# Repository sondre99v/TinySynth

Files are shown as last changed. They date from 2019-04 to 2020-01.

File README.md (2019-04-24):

# TinySynth
A business card with a digital synthesizer, built with the [ATtiny817](https://www.microchip.com/wwwproducts/en/ATTINY817) microcontroller.

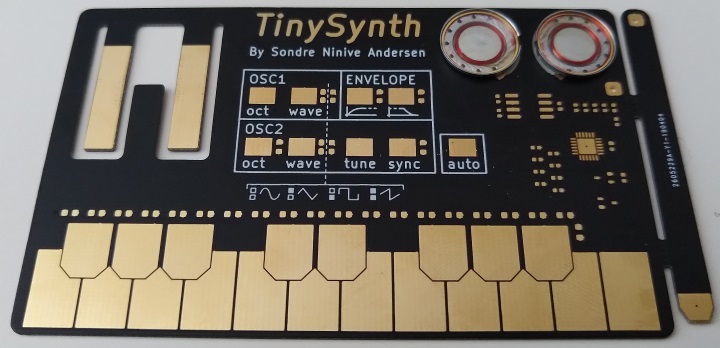
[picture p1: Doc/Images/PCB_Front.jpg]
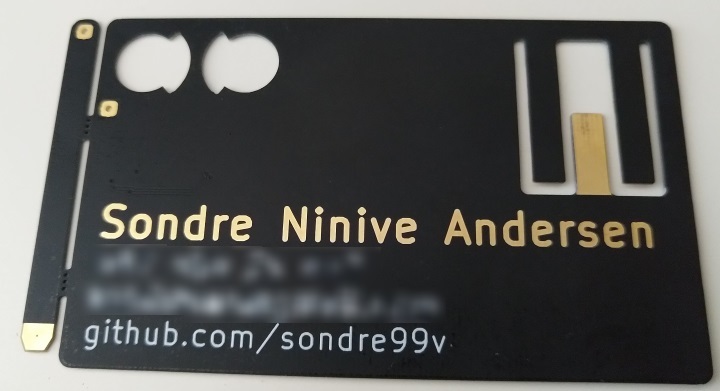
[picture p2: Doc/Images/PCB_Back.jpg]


## Features
The business card features my name, contact information, and a digital synthesizer with integrated speakers and keyboard. To use the synthesizer, insert a suitable 3V coin cell battery (CR2016 or CR2032 works), and break off the stylus on the right side of the card. The stylus can then be used to play the keyboard, or to configure the synthesizer with the buttons above the keys.

### Configuration
The synthesizer can be configured using the buttons above the keys. The buttons, from 1 to 8 have the following functions:
  * Oscillator 1 octave: Cycle the octave of oscillator 1 between three settings
  * Oscillator 1 wavefrom: Cycle the waveform of oscillator 1 between sine, square, triangle, and sawtooth
  * Envelope rise time: Toggle slow attack on the envelope
  * Envelope fall time: Toggle slow release on the envelope
  * Oscillator 2 octave / disable: Cycle the octave of oscillator 2 between three settings, or disable oscillator 2
  * Oscillator 2 waveform: Cycle the waveform of oscillator 2 between sine, square, triangle, and sawtooth
  * Oscillator 2 detuning: Cycle the interval of oscillator 2 (above oscillator 1) between unison, third, fifth, and seventh
  * Oscillator 2 synchronize: Enable oscillator 2 reset on each completed period of oscillator 1
    
## Hardware
### Keyboard
The keyboard is designed to be read by the microcontroller with an ADC input. The current keyboard is the third revision of the circuit. 

The first design used a simple voltage divider with an 100 ohm resistor between each key, to generate a unique voltage on each key. The stylus was connected to the ADC input, and was used to sample the voltages. This did not work very well, as a very weak pull-resistor was needed on the stylus, but it was weak enough that just touching it caused disturbance to the voltage.

The second design was more similar to the traditional method used for analog synthesizers. The keys was again connected with 100 ohm resistors, but this time a simple current-mirror circuit was used to drive a constant current through the chain. The stylus was grounded, and when touched to a key it provided a shorter circuit to ground lowering the voltage needed to drive this current. This current was then measured by the ADC. This worked, but was sensitive to changes in supply voltage, and did not give very reliable measurements.

The third and current revision is similar to the second design, but it replaces the constant current driver with a simple resistor. The keyboard forms a simple voltage divider with a fixed top resistor of 10K ohm, and the resistor chain between the keys makes up the bottom resistor. As the sampled voltage is non-linearly related to the bottom resistor, the resistor values betwwen the keys were adjusted to compensate. Some non-linearity was allowed (and is corrected for in the software) to allow use of standard resistor values, and reduce the number of unique BOM items.

### Speakers
The speakers are very thin speakers which I believe is intended to be used in earbuds. They are connected in series, and driven using a speaker-driver amplifying the filtered output signal from the DAC in the microcontroller.

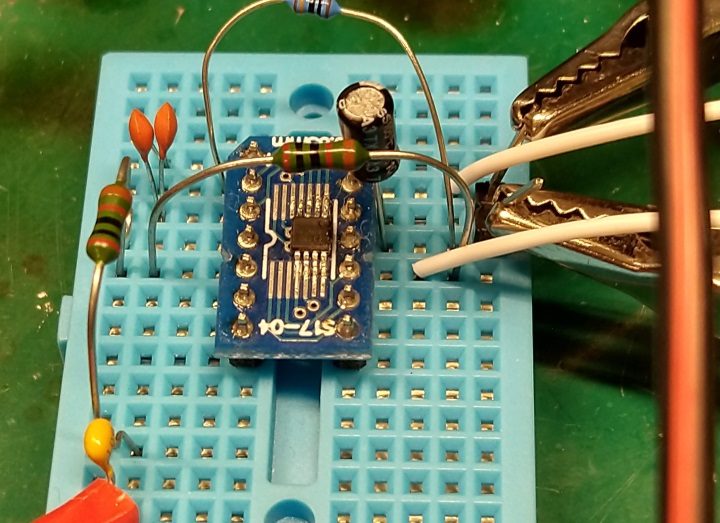
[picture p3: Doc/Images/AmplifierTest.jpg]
Prototyping of the amplifier circuit


### Battery
The battery holder was designed into the PCB to allow the business card to remain as thin as possible. Some testing was done in advance (by dremeling a 1.6mm PCB to test-fit a battery) but mostly the design was copied from various online inspirations. This design worked really well on the first prototype PCB, so no modification was required, other than to add an indication of the correct polarity of the battery.

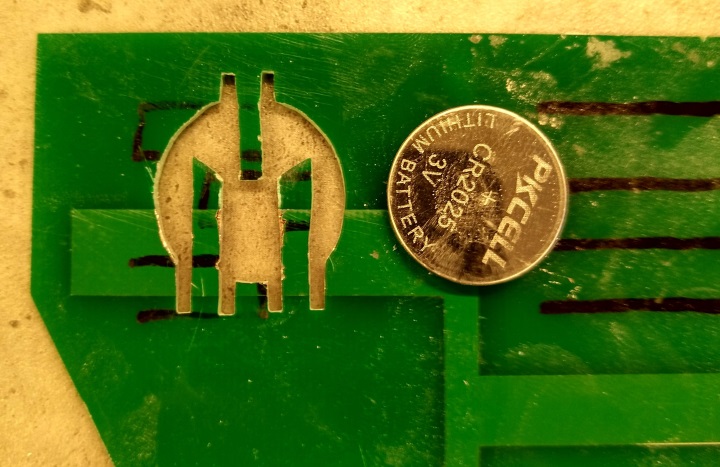
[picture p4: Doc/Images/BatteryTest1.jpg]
Initial test of battery holder
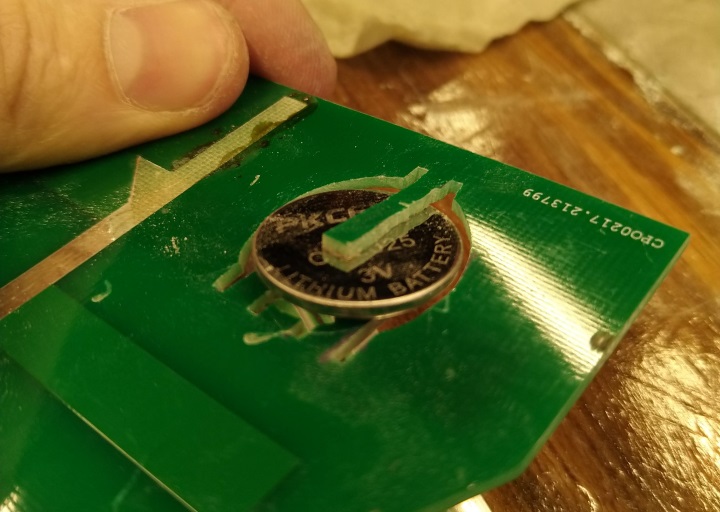
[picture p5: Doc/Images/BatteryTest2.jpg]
Initial test of battery holder
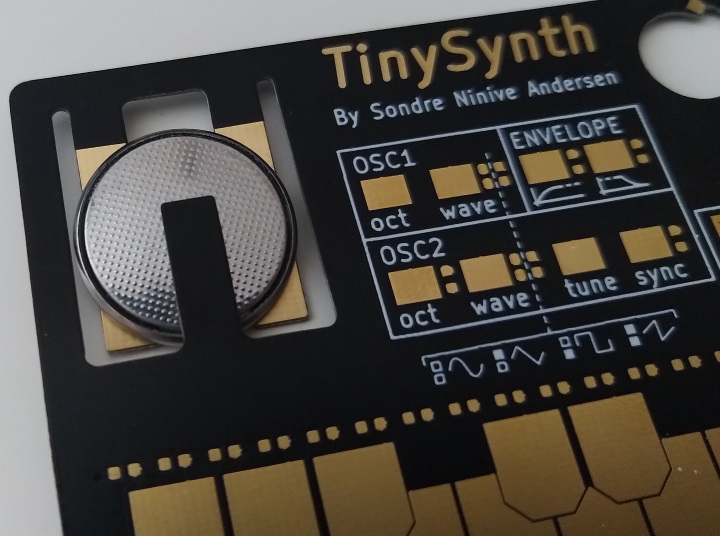
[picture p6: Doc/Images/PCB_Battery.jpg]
Battery holder on revision 1


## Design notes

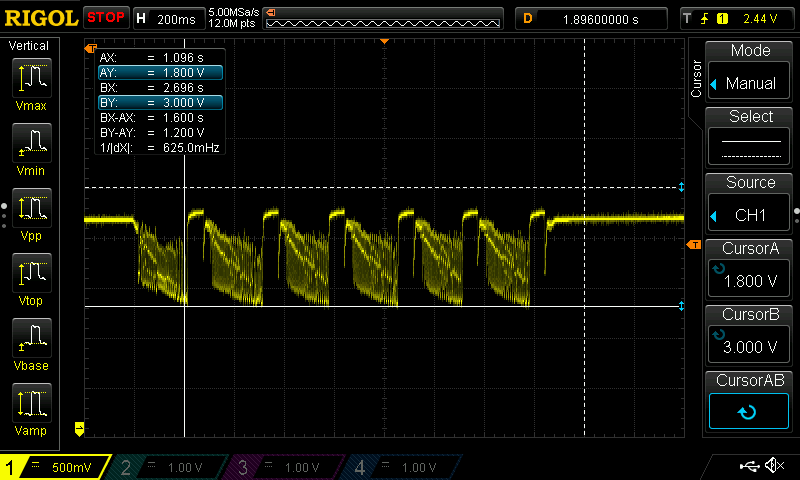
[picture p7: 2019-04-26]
Doc/Images/VoltageDrop/2_BattLow_BOD.png

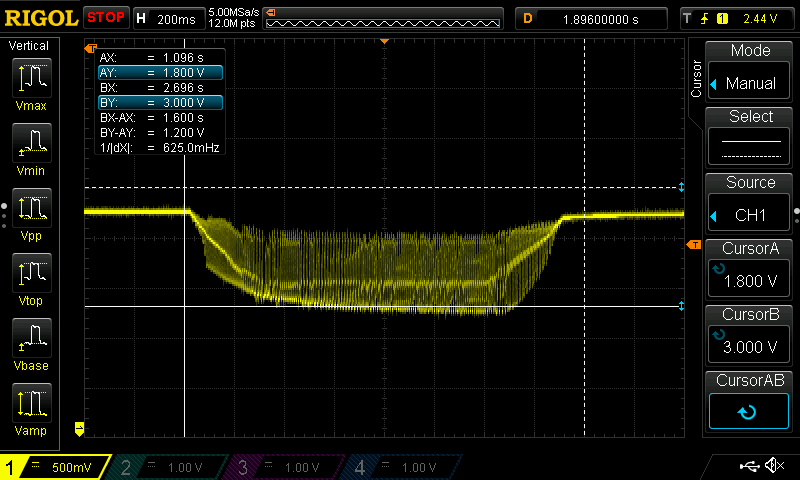
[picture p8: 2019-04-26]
Doc/Images/VoltageDrop/3_BattLow_NoBOD.png

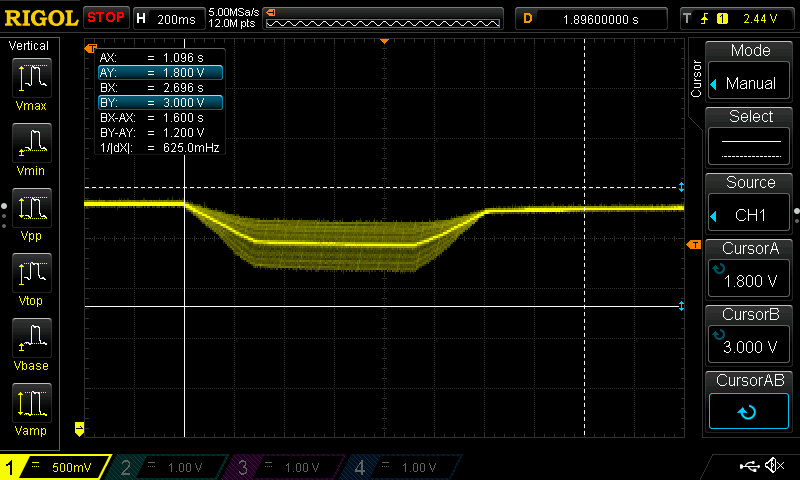
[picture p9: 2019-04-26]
Doc/Images/VoltageDrop/1_BattOK.png

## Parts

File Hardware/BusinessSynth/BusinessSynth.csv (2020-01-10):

Reference | Quantity | Value | Footprint | Datasheet
BT1 | 1 | Battery_Cell | BusinessSynth:BatteryHolderPCB_CR20xx | ~
C1 C4 | 2 | 100nF | Capacitor_SMD:C_0402_1005Metric | ~
C2 | 1 | Cfb | Capacitor_SMD:C_0402_1005Metric | ~
C3 | 1 | 1µF | Capacitor_SMD:C_0402_1005Metric | ~
C5 | 1 | 0.47µF | Capacitor_SMD:C_0402_1005Metric | ~
C6 | 1 | Cf_lp | Capacitor_SMD:C_0402_1005Metric | ~
D1 D8 D7 D6 D5 D4 D3 D2 | 8 | LED | BusinessSynth:LED_0603_1608Metric_nosilk | ~
H2 H1 | 2 | Stylus | Connector_Wire:SolderWirePad_1x01_Drill0.8mm | ~
H3 | 1 | Strain relief | MountingHole:MountingHole_2.1mm | ~
J1 | 1 | UPDI | Connector_PinHeader_2.54mm:PinHeader_1x03_P2.54mm_Vertical | ~
J2 J3 J4 J5 J6 J7 J8 J9 | 8 | StylusKey | BusinessSynth:StylusKey
LS1 LS2 | 2 | Speaker | BusinessSynth:CDMG13008L-02 | ~
R1 R2 R4 R3 | 4 | 680R | BusinessSynth:R_0603_1608Metric_nosilk | ~
R11 R10 | 2 | 2K2 | BusinessSynth:R_0603_1608Metric_nosilk | ~
R13 R12 | 2 | 3K3 | BusinessSynth:R_0603_1608Metric_nosilk | ~
R14 R15 | 2 | 6K8 | BusinessSynth:R_0603_1608Metric_nosilk | ~
R16 | 1 | 10K | BusinessSynth:R_0603_1608Metric_nosilk | ~
R17 | 1 | 15K | BusinessSynth:R_0603_1608Metric_nosilk | ~
R18 | 1 | 33K | BusinessSynth:R_0603_1608Metric_nosilk | ~
R19 | 1 | 100K | BusinessSynth:R_0603_1608Metric_nosilk | ~
R21 | 1 | 10K | Resistor_SMD:R_0402_1005Metric | ~
R23 R22 | 2 | 20K | Resistor_SMD:R_0402_1005Metric | ~
R24 | 1 | Rf_lp | Resistor_SMD:R_0402_1005Metric | ~
R25 | 1 | 0R | Resistor_SMD:R_0402_1005Metric | ~
R26 R27 R28 R29 R30 R31 R32 R33 | 8 | 330R | Resistor_SMD:R_0402_1005Metric | ~
R6 R5 R7 | 3 | 1K | BusinessSynth:R_0603_1608Metric_nosilk | ~
R8 R9 | 2 | 1K5 | BusinessSynth:R_0603_1608Metric_nosilk | ~
U1 | 1 | ATtiny817-M | BusinessSynth:QFN-24-1EP_4x4mm_P0.5mm_EP2.6x2.6mm_nosilk | http://ww1.microchip.com/downloads/en/DeviceDoc/40001901B.pdf
U2 | 1 | IS31AP4991A | BusinessSynth:MSOP-8-1EP_3x3mm_P0.65mm_nosilk

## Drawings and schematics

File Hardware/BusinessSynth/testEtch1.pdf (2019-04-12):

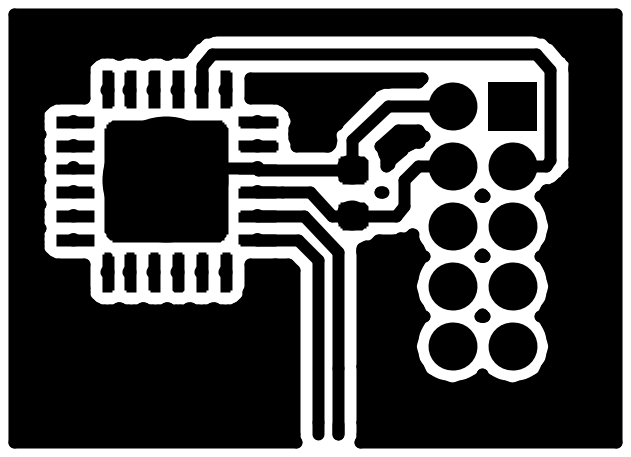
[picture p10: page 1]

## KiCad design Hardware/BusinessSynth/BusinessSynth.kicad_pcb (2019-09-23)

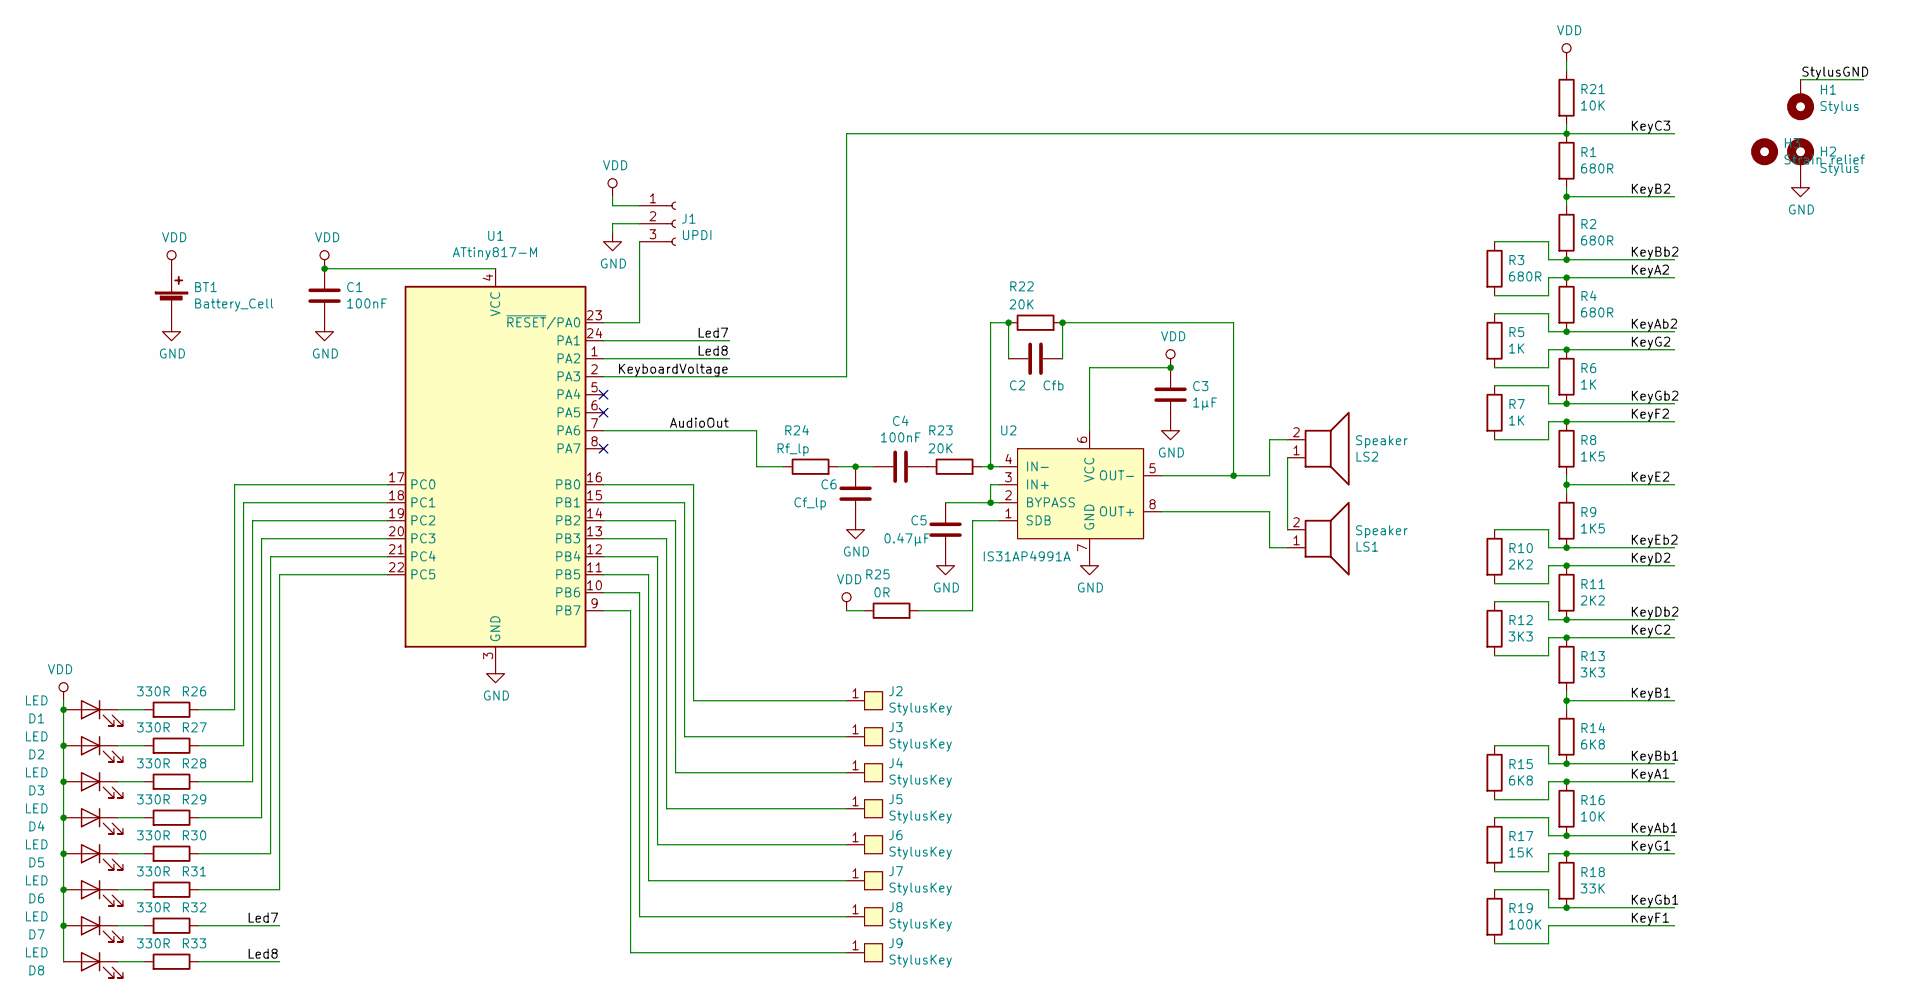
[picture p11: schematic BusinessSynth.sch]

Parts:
BT1: Battery_Cell; BatteryHolderPCB_CR20xx
C1, C4: 100nF; C_0402_1005Metric
C2: Cfb; C_0402_1005Metric
C3: 1µF; C_0402_1005Metric
C5: 0.47µF; C_0402_1005Metric
C6: Cf_lp; C_0402_1005Metric
D1, D2, D3, D4, D5, D6, D7, D8: LED; LED_0603_1608Metric_nosilk
H1, H2: Stylus; SolderWirePad_1x01_Drill0.8mm
H3: Strain relief; MountingHole_2.1mm
J1: UPDI; PinHeader_1x03_P2.54mm_Vertical
J2, J3, J4, J5, J6, J7, J8, J9: StylusKey
LS1, LS2: Speaker; CDMG13008L-02
R1, R2, R3, R4: 680R; R_0603_1608Metric_nosilk
R5, R6, R7: 1K; R_0603_1608Metric_nosilk
R8, R9: 1K5; R_0603_1608Metric_nosilk
R10, R11: 2K2; R_0603_1608Metric_nosilk
R12, R13: 3K3; R_0603_1608Metric_nosilk
R14, R15: 6K8; R_0603_1608Metric_nosilk
R16: 10K; R_0603_1608Metric_nosilk
R17: 15K; R_0603_1608Metric_nosilk
R18: 33K; R_0603_1608Metric_nosilk
R19: 100K; R_0603_1608Metric_nosilk
R21: 10K; R_0402_1005Metric
R22, R23: 20K; R_0402_1005Metric
R24: Rf_lp; R_0402_1005Metric
R25: 0R; R_0402_1005Metric
R26, R27, R28, R29, R30, R31, R32, R33: 330R; R_0402_1005Metric
U1: ATtiny817-M; QFN-24-1EP_4x4mm_P0.5mm_EP2.6x2.6mm_nosilk
U2: IS31AP4991A; MSOP-8-1EP_3x3mm_P0.65mm_nosilk

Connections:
/AudioOut: R24.1, U1.7 (PA6)
/KeyA1: R15.2, R16.1
/KeyA2: R3.2, R4.1
/KeyAb1: R16.2, R17.1
/KeyAb2: R4.2, R5.1
/KeyB1: R13.2, R14.1
/KeyB2: R1.2, R2.1
/KeyBb1: R14.2, R15.1
/KeyBb2: R2.2, R3.1
/KeyC2: R12.2, R13.1
/KeyC3: R1.1, R21.2, U1.2 (PA3)
/KeyD2: R10.2, R11.1
/KeyDb2: R11.2, R12.1
/KeyE2: R8.2, R9.1
/KeyEb2: R9.2, R10.1
/KeyF1: R19.2
/KeyF2: R7.2, R8.1
/KeyG1: R17.2, R18.1
/KeyG2: R5.2, R6.1
/KeyGb1: R18.2, R19.1
/KeyGb2: R6.2, R7.1
/Led7: R32.1, U1.24 (PA1)
/Led8: R33.1, U1.1 (PA2)
/StylusGND: H1.1
GND: BT1.2 (-), C1.2, C3.2, C5.2, C6.2, H2.1, J1.2, U1.3 (GND), U1.25 (GND), U2.7 (GND)
unnamed: C2.1, LS2.2, R22.2, U2.5 (OUT-)
unnamed: C2.2, R22.1, R23.2, U2.4 (IN-)
unnamed: C4.1, R23.1
unnamed: C4.2, C6.1, R24.2
unnamed: C5.1, U2.2 (BYPASS), U2.3 (IN+)
unnamed: D1.1 (K), R26.2
unnamed: D2.1 (K), R27.2
unnamed: D3.1 (K), R28.2
unnamed: D4.1 (K), R29.2
unnamed: D5.1 (K), R30.2
unnamed: D6.1 (K), R31.2
unnamed: D7.1 (K), R32.2
unnamed: D8.1 (K), R33.2
unnamed: J1.3, U1.23 (~RESET~/PA0)
unnamed: J2.1, U1.16 (PB0)
unnamed: J3.1, U1.15 (PB1)
unnamed: J4.1, U1.14 (PB2)
unnamed: J5.1, U1.13 (PB3)
unnamed: J6.1, U1.12 (PB4)
unnamed: J7.1, U1.11 (PB5)
unnamed: J8.1, U1.10 (PB6)
unnamed: J9.1, U1.9 (PB7)
unnamed: LS1.1, U2.8 (OUT+)
unnamed: LS1.2, LS2.1
unnamed: R25.2, U2.1 (SDB)
unnamed: R26.1, U1.17 (PC0)
unnamed: R27.1, U1.18 (PC1)
unnamed: R28.1, U1.19 (PC2)
unnamed: R29.1, U1.20 (PC3)
unnamed: R30.1, U1.21 (PC4)
unnamed: R31.1, U1.22 (PC5)
VDD: BT1.1 (+), C1.1, C3.1, D1.2 (A), D2.2 (A), D3.2 (A), D4.2 (A), D5.2 (A), D6.2 (A), D7.2 (A), D8.2 (A), J1.1, R21.1, R25.1, U1.4 (VCC), U2.6 (VCC)

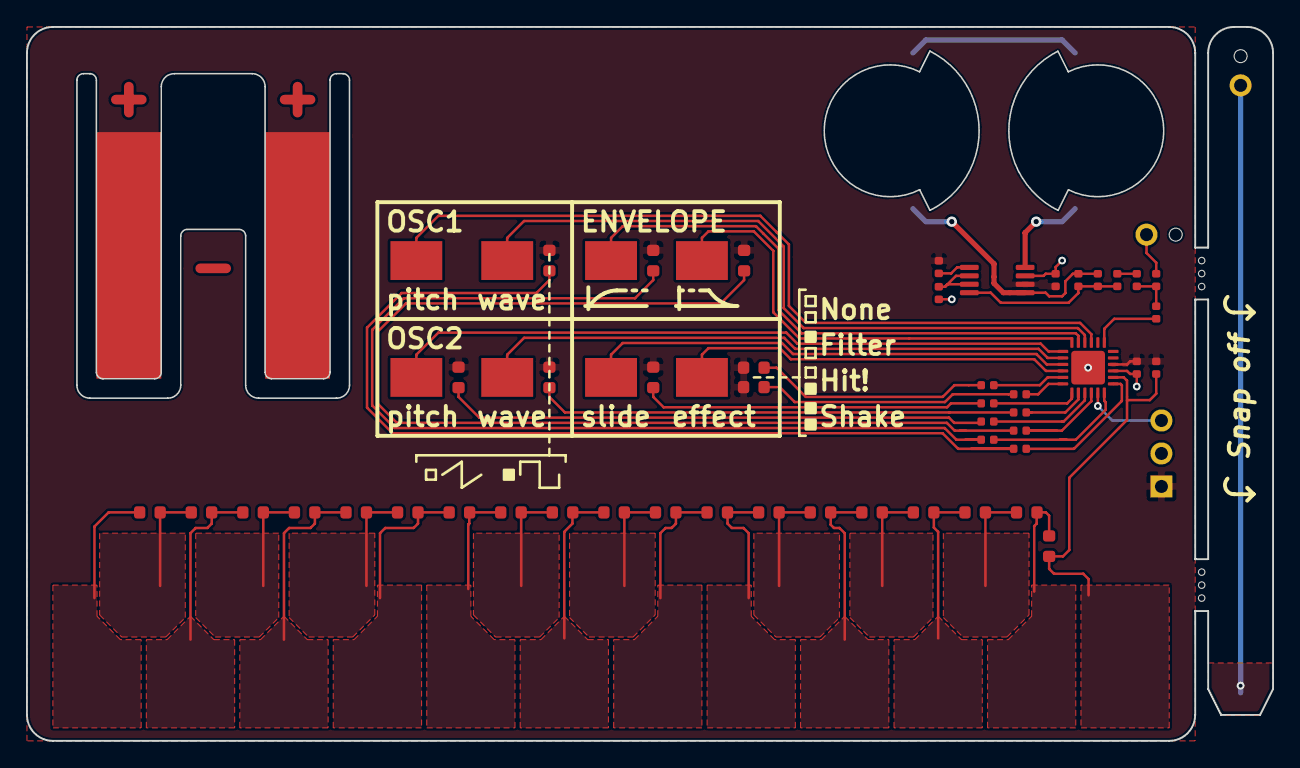
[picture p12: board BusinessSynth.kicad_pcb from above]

Board: 2 copper layers, 96.0 x 55.0 mm, 64 parts (0 on the bottom side), 55 nets.

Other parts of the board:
H3#2: Strain relief; MountingHole_2.1mm

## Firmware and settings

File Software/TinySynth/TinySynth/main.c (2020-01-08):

/*
 * TinySynth.c
 *
 * Created: 12/04/19 17:22:15
 * Author : Sondre
 */

#include <avr/io.h>
#include <avr/interrupt.h>

#include "Modules/oscillator.h"
#include "Modules/keyboard.h"
#include "Modules/envelope.h"
#include "Modules/lfo.h"
#include "Modules/patch_panel.h"
#include "Modules/patch.h"

#define TIME_TIMER_PERIOD 6250 // Gives 100Hz frequency with 20MHz clock and 32x prescaler

volatile static uint8_t update_pending = 0;

ISR(TCD0_OVF_vect) {
	TCD0.INTFLAGS = 0x01;
	update_pending = 1;
}

extern uint8_t gate_value;

int main(void)
{
	// Disable main clock prescaler to get 10MHz speed
	CCP = CCP_IOREG_gc;
	CLKCTRL.MCLKCTRLB = 1;

	// Setup TCD0 to give a 100Hz interrupt
	TCD0.CMPBCLR = TIME_TIMER_PERIOD;
	TCD0.INTCTRL = TCD_OVF_bm;
	TCD0.CTRLA = TCD_CNTPRES_DIV32_gc | TCD_ENABLE_bm;

	oscillator_init();
	oscillator_set_sources(OSCILLATOR_A, &(KEYBOARD_1->note_value), &(KEYBOARD_1->bend_value), &(LFO_1->value), &(ENVELOPE_1->value));
	oscillator_set_sources(OSCILLATOR_B, &(KEYBOARD_1->note_value), &(KEYBOARD_1->bend_value), &(LFO_1->value), &(ENVELOPE_2->value));

	keyboard_init(KEYBOARD_1);
	envelope_init(ENVELOPE_1);
	envelope_init(ENVELOPE_2);
	//envelope_init(ENVELOPE_3);
	lfo_init(LFO_1);
	ENVELOPE_1->gate_source = &(KEYBOARD_1->gate_value);
	ENVELOPE_1->trigger_source = &(KEYBOARD_1->trigger_value);
	ENVELOPE_2->gate_source = &(KEYBOARD_1->gate_value);
	ENVELOPE_2->trigger_source = &(KEYBOARD_1->trigger_value);
	ENVELOPE_3->gate_source = &(KEYBOARD_1->gate_value);
	ENVELOPE_3->trigger_source = &(KEYBOARD_1->trigger_value);

	patch_panel_init();
	patch_init();

	sei();

	while (1)
    {
		if (update_pending) {
			patch_panel_update();
			keyboard_update(KEYBOARD_1);
			lfo_update(LFO_1);
			oscillator_update(OSCILLATOR_A);
			oscillator_update(OSCILLATOR_B);
			envelope_update(ENVELOPE_1);
			envelope_update(ENVELOPE_2);
			envelope_update(ENVELOPE_3);
			update_pending = 0;
		}
    }
}

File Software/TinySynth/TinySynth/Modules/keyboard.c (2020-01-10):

/*
 * keyboard.c
 *
 * Created: 13/04/19 18:20:08
 *  Author: Sondre
 */

#include "keyboard.h"

#include <avr/io.h>


#define SLIDE_SPEED 12

typedef struct {
	keyboard_t public;
	uint8_t gate_pulse_timer;
	bool slide_enabled;
} keyboard_data_t;

static keyboard_data_t KEYBOARD_DATA_1 = {.public.note_value = 60};

keyboard_t* const KEYBOARD_1 = (keyboard_t*)&KEYBOARD_DATA_1;

void keyboard_init(keyboard_t* keyboard)
{
	ADC0.CTRLA = ADC_RESSEL_8BIT_gc | ADC_ENABLE_bm;
	ADC0.CTRLC = ADC_SAMPCAP_bm | ADC_REFSEL_VDDREF_gc | ADC_PRESC_DIV64_gc;
	ADC0.MUXPOS = ADC_MUXPOS_AIN3_gc;
}

static const uint8_t thresholds[20] = {
	8, 24, 37, 49, 62, 76, 88, 100, 113, 126, 139, 152, 164, 177, 191, 202, 213, 224, 236, 249
};

uint16_t current_notex128 = 60 * 128;
uint16_t target_notex128 = 60 * 128;


void keyboard_update(keyboard_t* keyboard)
{
	static uint8_t prev_adc = 255;
	
	uint8_t prev_gate = keyboard->gate_value;

	keyboard_data_t* data = (keyboard_data_t*)keyboard;

	ADC0.INTFLAGS = ADC_RESRDY_bm;
	ADC0.COMMAND = ADC_STCONV_bm;
	while (!(ADC0.INTFLAGS & ADC_RESRDY_bm)) { }
		
	volatile uint8_t adc_value = ADC0.RES;

	volatile int8_t key = 0;

	while(key < 20 && adc_value > thresholds[key]) {
		key++;
	}

	key = 19 - key;
	
	if (key >= 0) {
		target_notex128 = (key + 53) << 7;
	}

	if (data->slide_enabled) {
		if ((current_notex128 + SLIDE_SPEED) < target_notex128) {
			current_notex128 += SLIDE_SPEED;
		}
		else if ((current_notex128 - SLIDE_SPEED) > target_notex128) {
			current_notex128 -= SLIDE_SPEED;
		}
		else {
			current_notex128 = target_notex128;
		}
	}
	else {
		current_notex128 = target_notex128;
	}


	if (key >= 0) {
		data->public.gate_value = 1;
		data->public.note_value = current_notex128 >> 7;
		data->public.bend_value = current_notex128 & 0x7F;
	}
	else {
		data->public.gate_value = 0;
	}

	if (data->gate_pulse_timer > 0) {
		data->public.gate_value = 1;
		data->gate_pulse_timer--;
	}

	data->public.trigger_value = data->public.gate_value && !prev_gate;
}

void keyboard_pulse_gate(keyboard_t* keyboard)
{
	keyboard_data_t* data = (keyboard_data_t*)keyboard;
	data->gate_pulse_timer = 100;
}

void keyboard_enable_slide(keyboard_t* keyboard)
{
	keyboard_data_t* data = (keyboard_data_t*)keyboard;
	data->slide_enabled = true;
}

void keyboard_disable_slide(keyboard_t* keyboard)
{
	keyboard_data_t* data = (keyboard_data_t*)keyboard;
	data->slide_enabled = false;
}

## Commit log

2019-02-19 Start moving oscillators to their own module
    [main.c]
2019-02-20 Fix some bugs causing no sound to be generated from oscillators
    [main.c]
2019-02-22 Fix move frequency changing out of ISR to fix timing issue
    [main.c]
2019-02-22 Fix mixing and levels of oscillators
    [main.c]
2019-03-04 Move to 16 bit waveform samples and amplitude. Bugged "envelope"
    [main.c]
2019-03-04 Move oscillator handling to separate function. Moved away from delta-based DAC output
    [main.c]
2019-04-12 Added PCB project to repository
    [BusinessSynth-B_Cu.gbr, BusinessSynth-B_Mask.gbr, BusinessSynth-B_SilkS.gbr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]
2019-04-12 Add Notes folder and excel sheet with resistor calculations
    [KeyResistorChain.xlsx]
2019-04-12 Draw new keyboard circuit in the KiCAD schematic
    [BusinessSynth.sch]
2019-04-14 Add code for envelope and keyboard modules
    [KeyResistorChain.xlsx]
2019-04-24 Change resistor chain in schematic to simpler solution
    [BusinessSynth.sch]
2019-04-24 Add Excel sheet with resistor calculations
    [KeyResistorChain.xlsx]
2019-04-24 Extend basic framework for synthesizer modules
2019-04-25 Change oscillators to use 8 bit values
    [main.c]
2019-04-25 Add config panel module
    [KeyResistorChain.xlsx]
2019-04-26 Add images of voltage measurements
2019-04-26 Wire up the rest of the patch panel
2019-06-24 Add noise waveform to oscillator
    [keyboard.c, main.c, patch_panel.c]
2019-06-24 Fix line endings and remove extra whitespace
    [keyboard.c, main.c]
2019-06-26 Add hold timer to envelope
2019-08-12 Add glide functionality to oscillator
    [BusinessSynth.kicad_pcb]
2019-08-23 Start layout of new patch-panel
    [BusinessSynth.kicad_pcb]
2019-08-24 Fix speaker-driver footprint, and complete new routing
    [BusinessSynth.kicad_pcb, BusinessSynth.sch]
2019-08-26 WIP: Connect filter and EG correctly
    [main.c]
2019-08-27 Fix modulation of filter
    [main.c]
2019-09-23 Finalize PCB for rev 2
    [BusinessSynth.kicad_pcb, BusinessSynth.sch]
2019-09-23 Generate gerbers for PCB rev 2
    [BusinessSynth-B_Cu.gbr, BusinessSynth-B_Mask.gbr, BusinessSynth-B_SilkS.gbr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]
2020-01-06 Remove led PWM and EG3 init values
2020-01-06 Fix patch panel for new PCB
    [patch_panel.c]
2020-01-07 Fix wave selection buttons for new PCB
2020-01-07 Fix pitch buttons for new PCB
    [keyboard.c]
2020-01-07 Add basic implementation of filter effect
2020-01-07 Improve implementation of filter effect
2020-01-08 Add hit effect and fix simultaneous slide and shake
    [main.c]
2020-01-08 Fix warnings and whitespace
    [keyboard.c, main.c]
2020-01-10 All features working
    [BusinessSynth.csv]
2020-01-10 Fix sliding not continuing when key is released
    [keyboard.c]
